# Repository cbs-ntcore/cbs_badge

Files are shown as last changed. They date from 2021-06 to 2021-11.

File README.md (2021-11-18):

This badge is designed to highlight digital fabrication techniques that are commonly
used in the [Neurotechnology Core](https://www.ntcore.org/)(NTCore) at the
[Center for Brain Science](http://cbs.fas.harvard.edu/) at Harvard University.

The NTCore works to accelerate and advance scientific progress through:
- design and fabrication of novel instrumentation
- user training and access to a shared fabrication space
- consultation on instrumentation use, design, fabrication, and purchase

By building a badge users will learn about:
- electronics design including making a custom printed circuit board (PCB) using the free and open source [KiCad](https://www.kicad.org/) design software
- electronics fabrication including soldering of surface mount electronics
- embedded programming using the [Arduino](https://www.arduino.cc/) environment
- designing mechanical parts using [Autodesk Fusion360](https://www.autodesk.com/products/fusion-360/) (free to academics)
- digital fabrication using 3D printing and laser cutting for rapid prototyping and production

We are happy to offer customized assistance. For the badge you can choose to:
- [Assemble pre-built parts](#assembling-your-badge)
- [Build (by soldering, laser cutting, etc...) and then assemble parts](#building-your-own-badge)
- Design your own parts (we're happy to help!)

# Assembling your badge

Your badge comes in 4 major parts and requires some minor assembly before use:
- Electronics
- Battery (CR2032)
- Laser cut case back cover
- 3D printed case

Below is a description of the assembly steps followed by a video of the assembly process.

- [ ] Install the battery into the electronics (positive side out).
- [ ] Insert the electronics into the case from the back making sure that the electronics slide behind the 6 plastic tabs.
- [ ] Slide the laser cut case back cover in place to lock the electronics into the case.
- [ ] Test the badge by pressing your finger against the two neurons at the bottom of the badge. If your hands are very dry you may need to slightly moisten your finger before touching the badge.

Click the image below for a short (~1 min) video showing the assembly process.

Assembly Video Link (https://www.youtube.com/watch?v=ZrBIpawWA10)

The hole at the top of the laser cut piece can be used to hang the badge from a lanyard, carabiner or cord.

If you are interested in more building experience, follow along with building the parts
of the badge.

# Building your own badge

Badge building involves 5 steps:
- [soldering electronic components to the badge printed circuit board](#soldering)
- [programming the microcontroller](#programming)
- [3D printing the main case body](#3d-printed-case)
- [laser cutting a custom case back cover](#lasercut-back-cover)
- [assembling your badge](#assembling-your-badge)

## Electronics

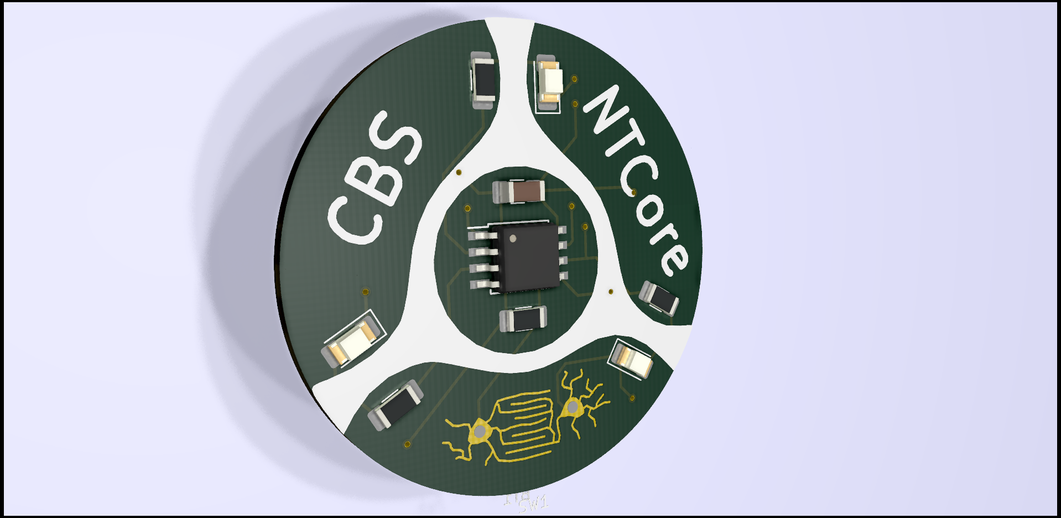
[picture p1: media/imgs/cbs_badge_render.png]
PCB Render Rough Render

### PCB
Although it is possible to fabricate your own printed circuit boards, the results are often less precise and more
time consuming than ordering a custom board. The cost of the board will depend on the difficulty in fabricating the design,
the lead time for the order and the quantity ordered. Designs that have traces (wires embedded in the PCB) that
are less than 6 mils (thousandths of an inch) or have many layers (pcbs are made by stacking layers of fiberglass, patterned
copper and other materials) are typically manufacturable at an increased cost or lead time. The design for this
badge is relatively simple and can be made by most low cost venders ('fab houses') including [OSHPark](https://oshpark.com/).
OSHPark is highly recommended as they produce high quality boards with a relatively short lead time (typically a week)
at a USA location allowing for overnight shipping. For their 'Prototype' service they charge $5 per square inch for a 2
layer PCB. The badge is 2.25 square inches costing $11.25 per board. When ordered with their 'Medium Run' bulk service
(which requires ordering at least 100 square inches) the cost drops to $2.25 per board.

### PCB and circuit design

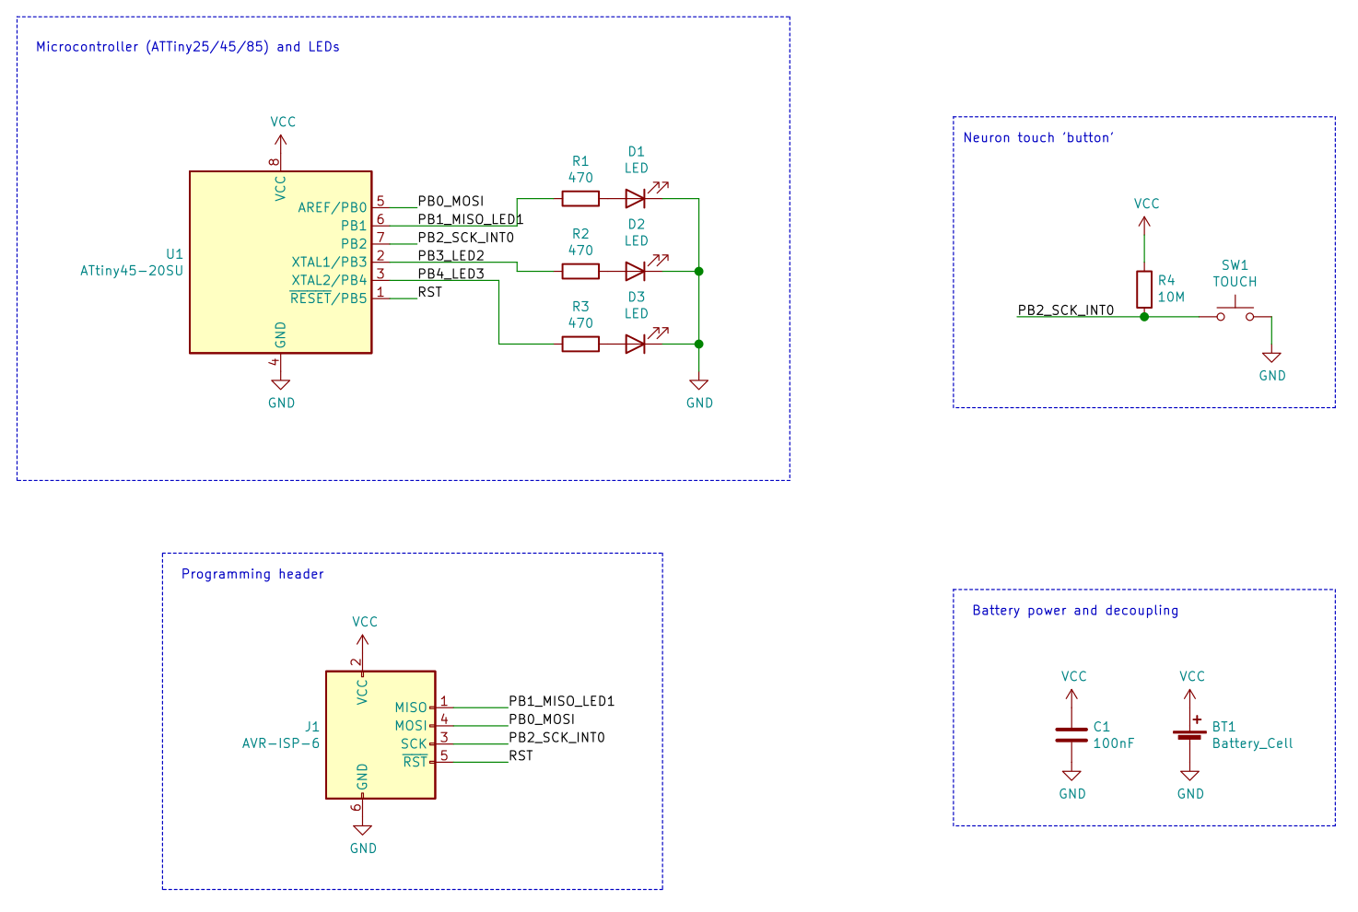
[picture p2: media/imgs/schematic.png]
schematic Schematic


[KiCad](https://www.kicad.org/) is a free and open source electronics design program that runs on all modern operating systems. It's design
process involves a number of steps often starting with making a schematic of the circuit you would like to build.
This schematic typically includes several components (including resistors, capacitors, connectors, integrated
circuits etc) connected using traces (wires embedded in the final PCB design). After a schematic is drawn some
automated tests should be run (electrical rules check or ERC) to check for incorrect or missing connections. The
final schematic and components can then be exported as a 'netlist', footprints (custom copper shapes that fit
specific components) can then be associated with the netlist components and then imported into the pcb
layout editor. In the pcb layout editor footprints are placed on a layered design (typical low cost boards
have 2 copper layers 'top' and 'bottom') and traces are drawn to connect footprints based on the connectivity
defined in the netlist. Before finalizing a design the pcb layout editor can run several automated checks
(design rule checks or DRC) to verify that your design matches the capabilities of the fab house (you will need
to input these design rules into the editor). Fab houses typically accept gerber files (a special file format
that contains images of layers of the pcb and other features needed for fabrication). However, some houses
including OSHPark will directly accept KiCad designs.

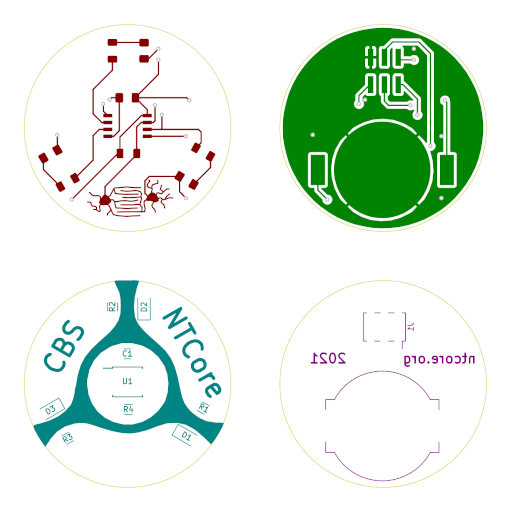
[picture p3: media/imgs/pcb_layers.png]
pcb PCB Layers


### Soldering

If you have not soldered before, [adafruit.com](adafruit.com) has a very good
[guide to soldering](https://learn.adafruit.com/adafruit-guide-excellent-soldering/surface-mount)
including tips on surface mount soldering.

All the electronic components are surface mount devices (SMD) which attach to
copper 'footprints' on the top or bottom of the badge.

It's often helpful to start with the shortest parts and solder the largest parts last
(connectors and in this case the battery tab). For this badge you might want to solder parts in the following order:
- ATTiny (U1): the black 8 pin chip that goes in the middle
- Capacitor (C1): the small tan colored device
- Resistors (R1-R4): a 106 (10 MOhm) resistor (R4) and 3 x 471 (470 Ohm) resistors one for each LED (R1-3)
- LEDs (D1-3): light emitting diodes, clear side up, green arrow down
- battery holder (on back): make sure the battery slides in from the edge of the badge

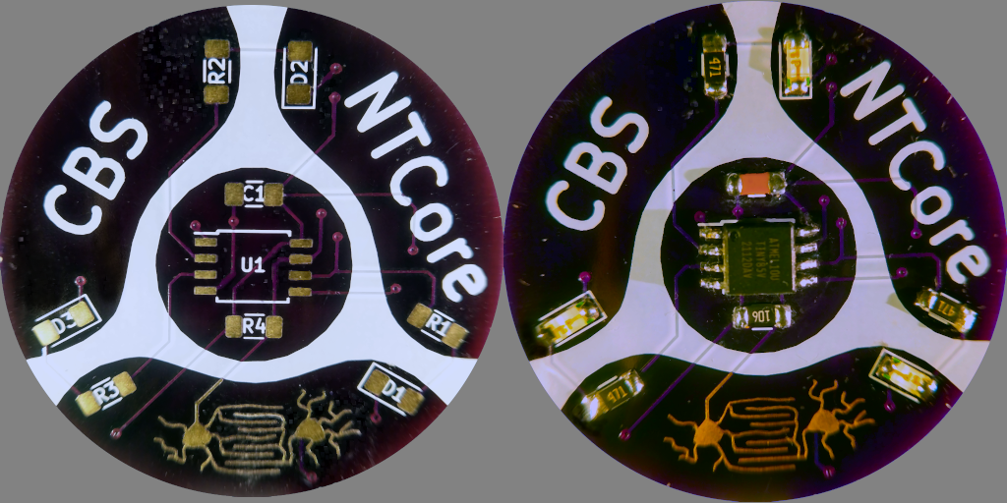
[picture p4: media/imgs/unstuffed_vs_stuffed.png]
Stuffed Board Stuffed board


Some parts (the LEDs and ATTiny) only work when connected in one orientation.
Be sure to connect:
- the pin on the ATTiny next to the dot to the pad marked with an extended line
- the green marked ends of the LEDs with the closed end of the lines

Soldering SMD electronics takes some practice and a few tips can make the
process much easier. One useful technique is to solder 1 pin at the corner
of a part. This pin can be reheated and the part position
adjusted with forceps while the solder is molten. When the part is correctly
aligned the opposite pin can be soldered to lock the part in place before
soldering the remaining pins.

It's time to solder the components on the front of the badge:
- [ ] U1: black 8 pin ATTiny, note the orientation
- [ ] C1: tan capacitor
- [ ] R4: 106 (10 MOhm) resistor
- [ ] R1: 471 (470 Ohm) resistor
- [ ] R2: 471 (470 Ohm) resistor
- [ ] R3: 471 (470 Ohm) resistor
- [ ] D1: LED, note the orientation
- [ ] D2: LED, note the orientation
- [ ] D3: LED, note the orientation

Finally, flip over the badge to prepare to solder on the battery clip.

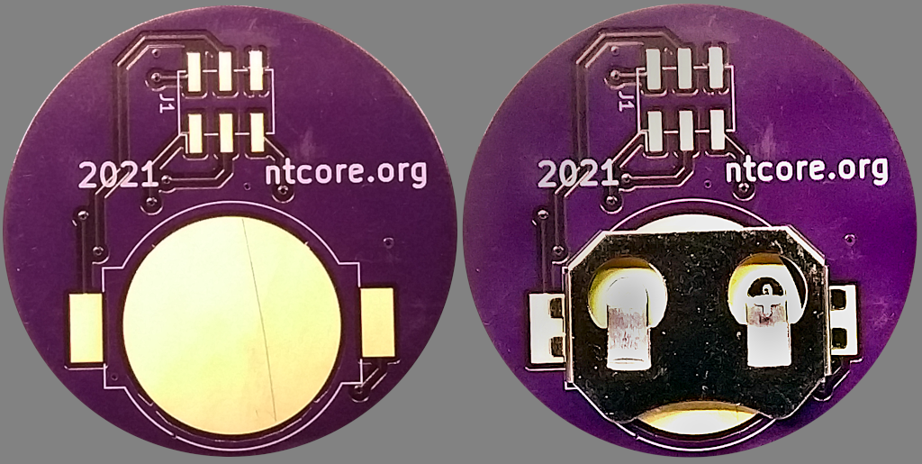
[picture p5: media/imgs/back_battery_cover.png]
Battery Cover


Solder the back battery holder taking care as the iron will quickly heat
up the entire metal clip. Allow the clip to cool down between applications of
heat while adjusting the clip. Be sure to add plenty of solder to create a
solid connection that will resist the spring force of the clip when the battery
is inserted.

## Software
### Programmable electronics using microcontrollers

The badge contains a microcontroller, a small computer designed to produce and sample digital
and analog signals. The microcontroller can be programmed (more on this below) to produce precisely
timed pulses, read and record analog voltages, control other electronics (lights, sensors, motors, etc),
perform complicated logic (state machines, event loops) and many other tasks. Many types of microcontrollers
are available with different amounts of processing power, number of connections and specialized hardware
(including wifi and other wireless communication). The badge circuit uses a simple and low cost ATTiny.
This ATTiny has only 8 connections (pins) and requires only a program and a connection to power and
ground to function. For the badge 3 pins are connected to light emitting diodes (LEDs) and one more pin
is connected to a custom neuron footprint used as a touch sensor.

### Embedded programming using Arduino

[Arduino](https://www.arduino.cc/) is a beginner friendly environment for writing programs for and configuring microcontrollers. There are
many official and non-official 'Arduino compatible' boards which can be programmed with the Arduino
integrated development environment (IDE). Arduino programs are written in the C++ programming language
and use functions that simplify the process of setting or reading the state of digital and analog pins
and other aspects of using a microcontroller. Development using Arduino starts with installing the IDE,
adding support for the board you'd like the use, installing any required libraries, and then writing
your program and 'uploading' it to your board. Most boards can be programmed over USB. However, the
badge uses a simpler method called 'in circuit serial programming' (ICSP) that requires a custom
programmer (such as the [Pocket AVR Programmer](https://www.sparkfun.com/products/9825) or 
[USBtinyISP](https://www.adafruit.com/product/46)). To compile code for the ATTiny you will need to
install support for the ATTiny from here: [https://github.com/damellis/attiny](https://github.com/damellis/attiny)

For a detailed course on using Arduino please see the
['Arduino for Biologists' nanocourse](https://github.com/HMS-RIC/ArduinoNanocourse).

neurongif Neuron firmware

The badge 'firmware' (software for embedded hardware) simulates 3 neurons connected in a ring with 3
model excitatory synapses. The spike output of each neuron is mapped to a different LED which flashes
when the neuron spikes. When the touch sensor (copper neurons at the bottom of the badge) is touched, the
microcontroller wakes up from 'sleep' (a low power mode where very few features are active) and 
initializes the neural network by setting the synaptic weights to a low value. As the network runs,
random simulated currents are injected into the 3 neurons causing them to initially spike in a random
pattern. These spikes trigger time-dependent changes in the synaptic weights. The lack of inhibition
and asymmetry in the plasticity causes unbound excitation in the circuit and the network often
quickly converges to a state of continuous fast firing. The network will continue to run as long
as the touch sensor is held. When the touch sensor is released the microcontroller will reenter
'sleep' mode to extend battery life.

### Programming

Make sure there is no battery in the badge (the programmer will power the
electronics). Press the badge against the programmer aligning the upper 
white portion of the logo with the notch in the programming jig as shown in the
image below.

Programming


While holding the badge in place run "Sketch->Upload Using Programmer" in the
Arduino program. Some of the LEDs should blink and when the program says
"Done uploading" your badge is programmed.

Remove the badge from the programmer, insert the battery and test the badge
by pressing the neurons at the bottom of the badge while not touching the
battery clip on the back.

## Case
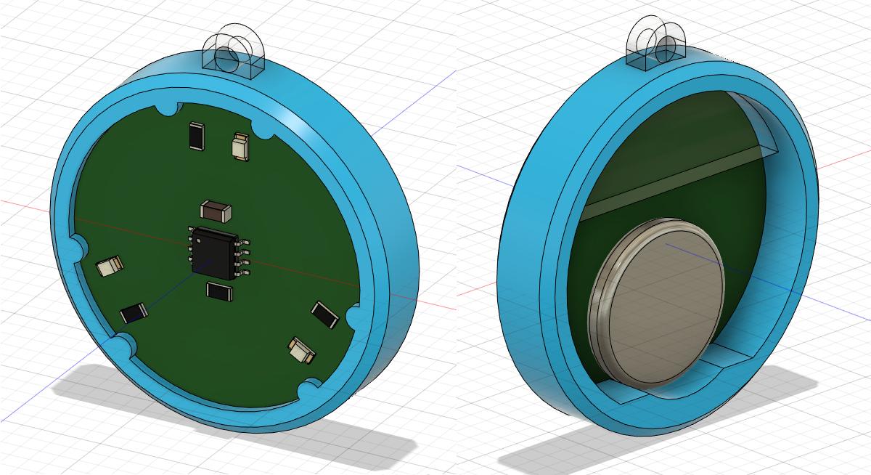
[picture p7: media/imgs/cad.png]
Case CAD


### Computer aided design (CAD) using Autodesk Fusion360

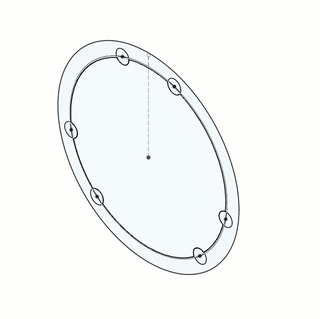
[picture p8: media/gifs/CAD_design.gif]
CAD CAD design


Although simple 2D mechanical parts can be designed in Inkscape, Adobe Illustrator or other vector
graphics programs, 3D parts and assemblies are often designed in specialized computer aided design
(CAD) software. The badge case was designed in [Autodesk Fusion360](https://www.autodesk.com/products/fusion-360/)
(free to academics) and involved a typical process where 2D sketches on reference planes are 'extruded' to form 3D shapes. Each
new 3D shape can be joined with previous shapes or be used to cut custom shaped holes out of existing
parts. This process creates a final (or multiple) 3D shapes and a recorded history of how these
parts were designed. This history can be edited and replayed to generate part revisions or to
adapt a single design to multiple applications. For the badge, 2 parts were designed: a 
case designed for easy 3D printing and a customizable back cover designed for laser cutting.

### 3D printed case

3D printing

3D printing is a relatively automated process for translating a digital design to a physical
object. Although many materials can be 3D printed with often very different processes, one of the
most common methods for 3D printing is fused deposition modeling (FDM) using a plastic filament, 
polylactic acid (PLA). FDM printing involves heating up and forcing (extruding) PLA through a
circular nozzle (0.4 mm in diameter) that is mounted to a XYZ movement system. By depositing
and fusing overlapping 2D layers, complex 3D shapes can be created. Preparing a design for FDM
printing involves:
- exporting a solid model (in STL file format) from your CAD software
- importing the STL into a 'slicer' program that:
    - cuts the model into 2D layers
    - adds any necessary support material to deal with unsupported overhangs (where a higher 2D layer has no plastic underneath
to join to)
    - generates a sequence of movements (GCODE) to command the 3D printer to make the part
- loading and running the GCODE on a suitable 3D printer
- finally removing any support material and finishing your part

### Lasercut back cover

Lasercutting is a common technique for cutting 2D shapes out of flat sheets of plastic (typically
acrylic). A high powered (75 watt) CO2 laser is focused on the surface of the plastic at a position
determined by computer controlled XY movement. This focused light quickly ablates the plastic
under the beam and by moving the cut position in various paths, flat 2D parts can be produced.
For simple designs, vector graphics programs (Inkscape, Adobe Illustrator, Corel Draw) can be used to simply
draw the paths the laser should follow and for more complex designs sketches can be exported from
CAD software in a suitable format (DXF). For most 2D geometries lasercutting is significantly
faster, more accurate and produced a better finished part compared to 3D printing.

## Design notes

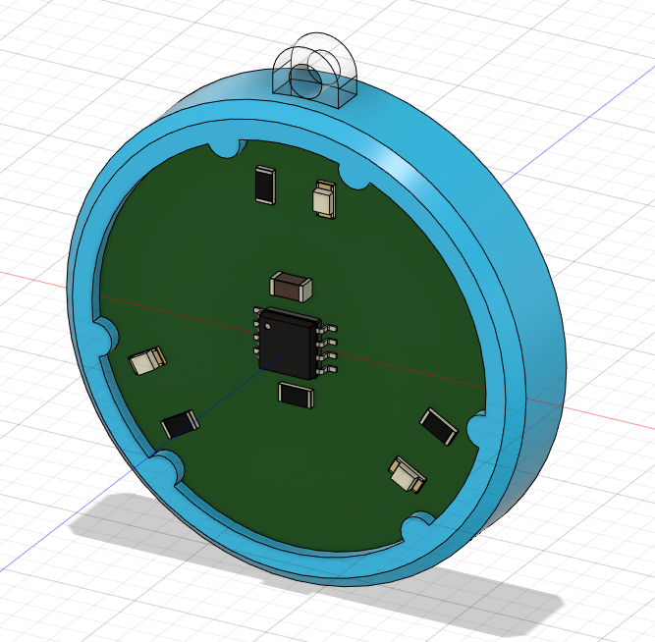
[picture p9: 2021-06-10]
media/imgs/cad_front.png

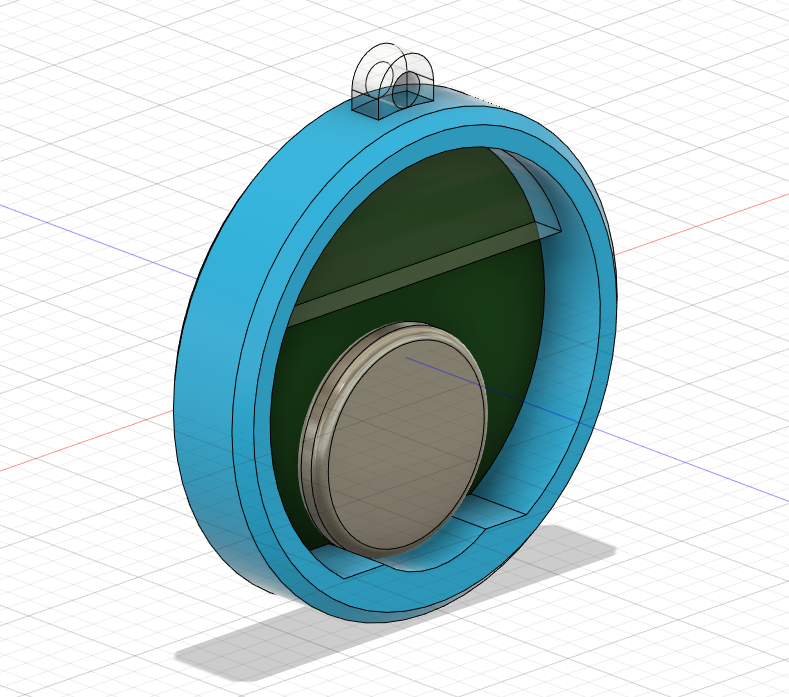
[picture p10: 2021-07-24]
media/imgs/cad_back.png

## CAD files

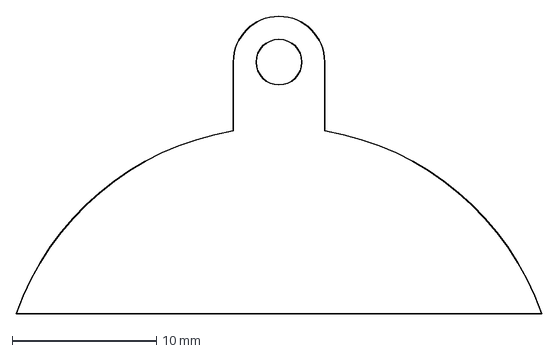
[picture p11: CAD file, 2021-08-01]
blank_back_case_cover.dxf
36.5 x 20.6 mm

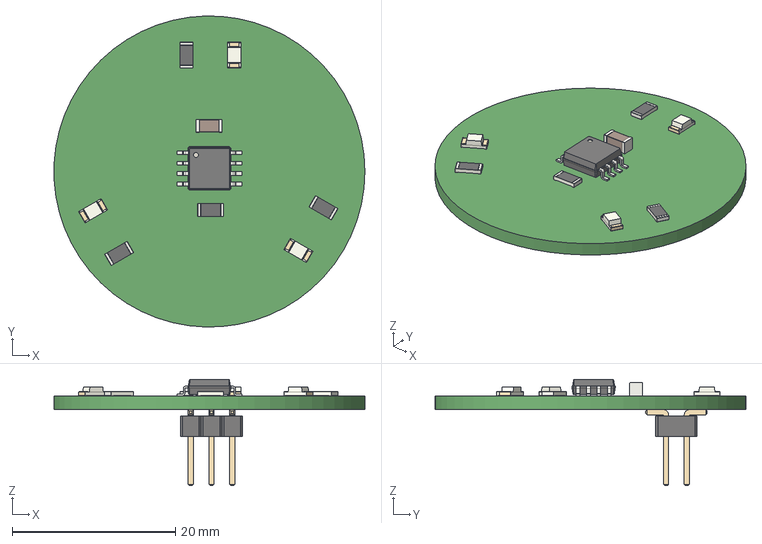
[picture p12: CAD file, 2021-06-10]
cbs_badge/cbs_badge.step
38.1 x 38.1 x 13.0 mm

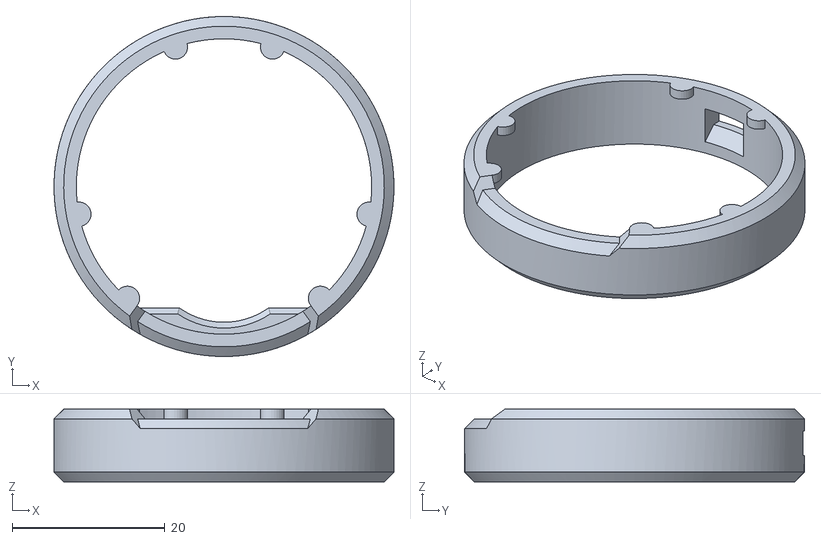
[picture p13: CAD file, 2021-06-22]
case.stl
44.4 x 44.5 x 9.53

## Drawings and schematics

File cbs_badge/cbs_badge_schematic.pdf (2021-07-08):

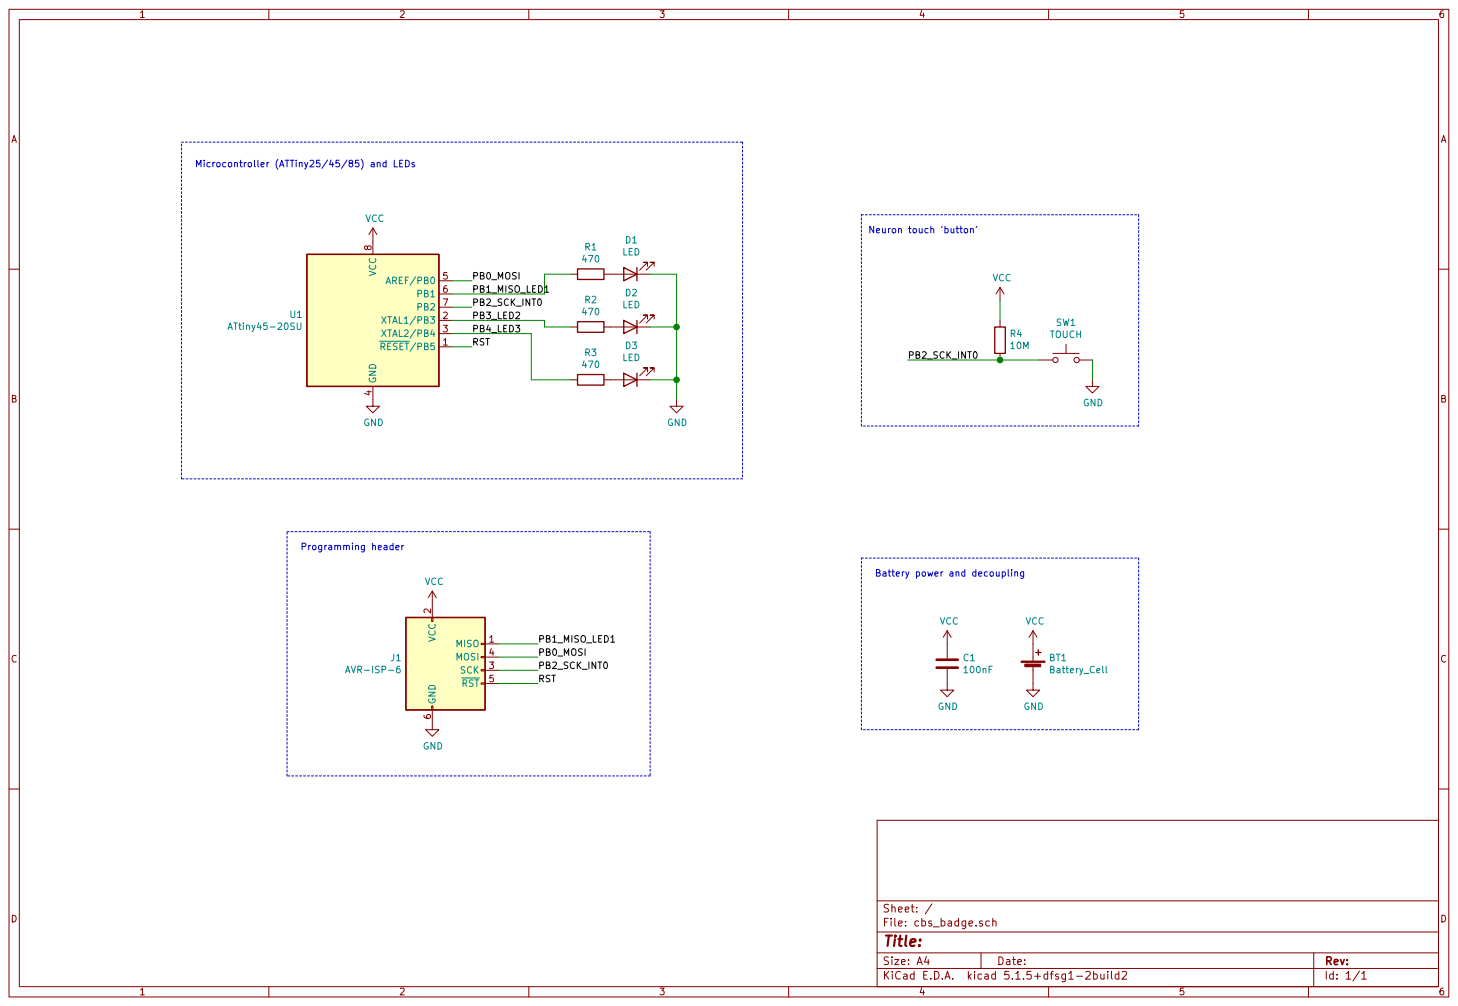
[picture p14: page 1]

Battery power and decoupling Neuron touch 'button' Microcontroller (ATTiny25/45/85) and LEDs

File: cbs_badge.sch Sheet: / GND

2 SCK 3 MOSI 4 RST 5 GND

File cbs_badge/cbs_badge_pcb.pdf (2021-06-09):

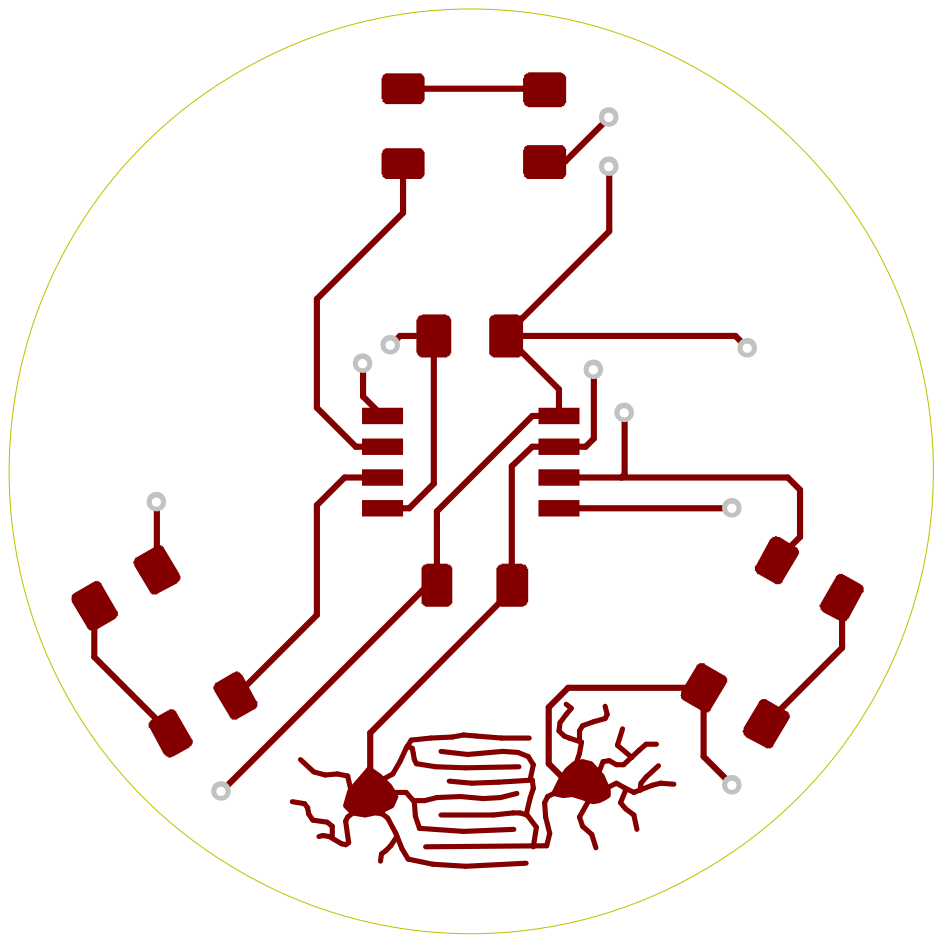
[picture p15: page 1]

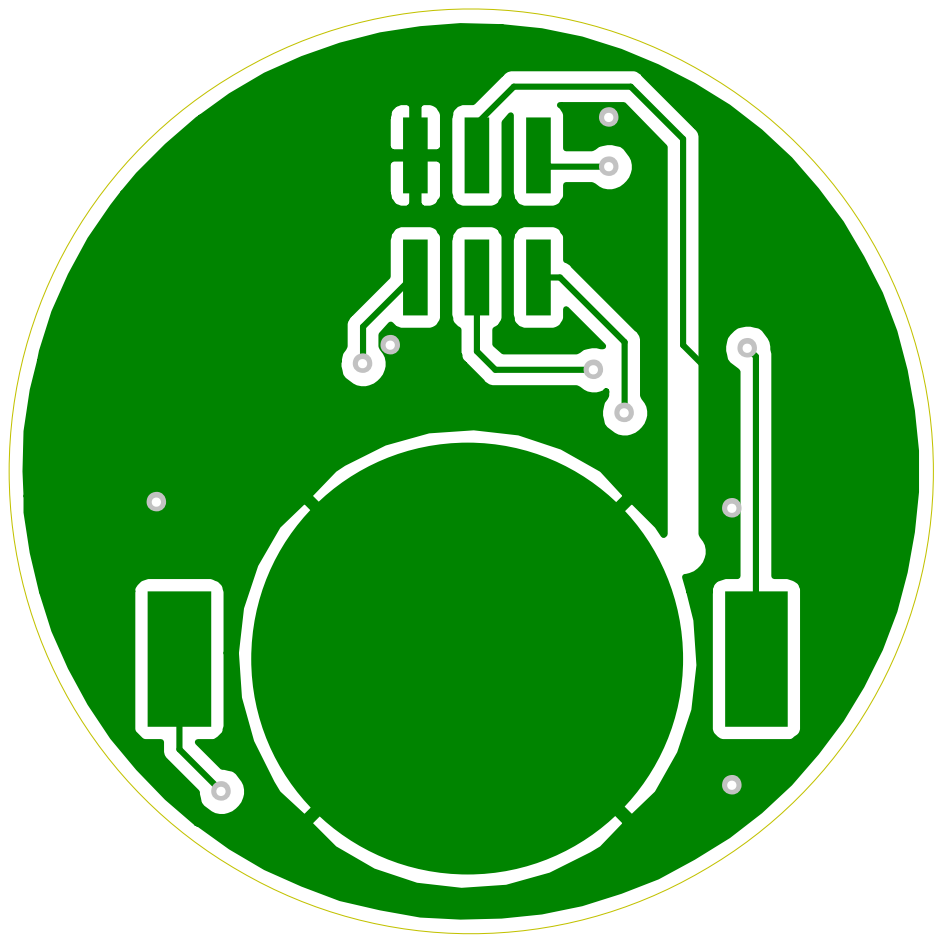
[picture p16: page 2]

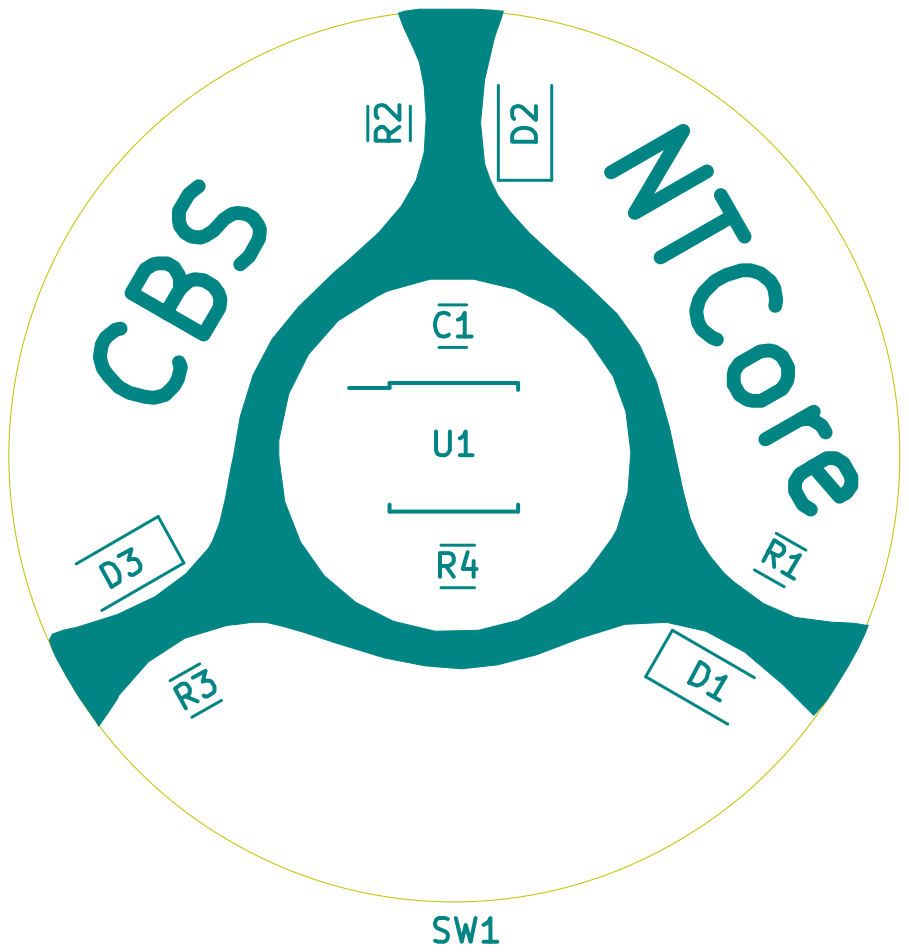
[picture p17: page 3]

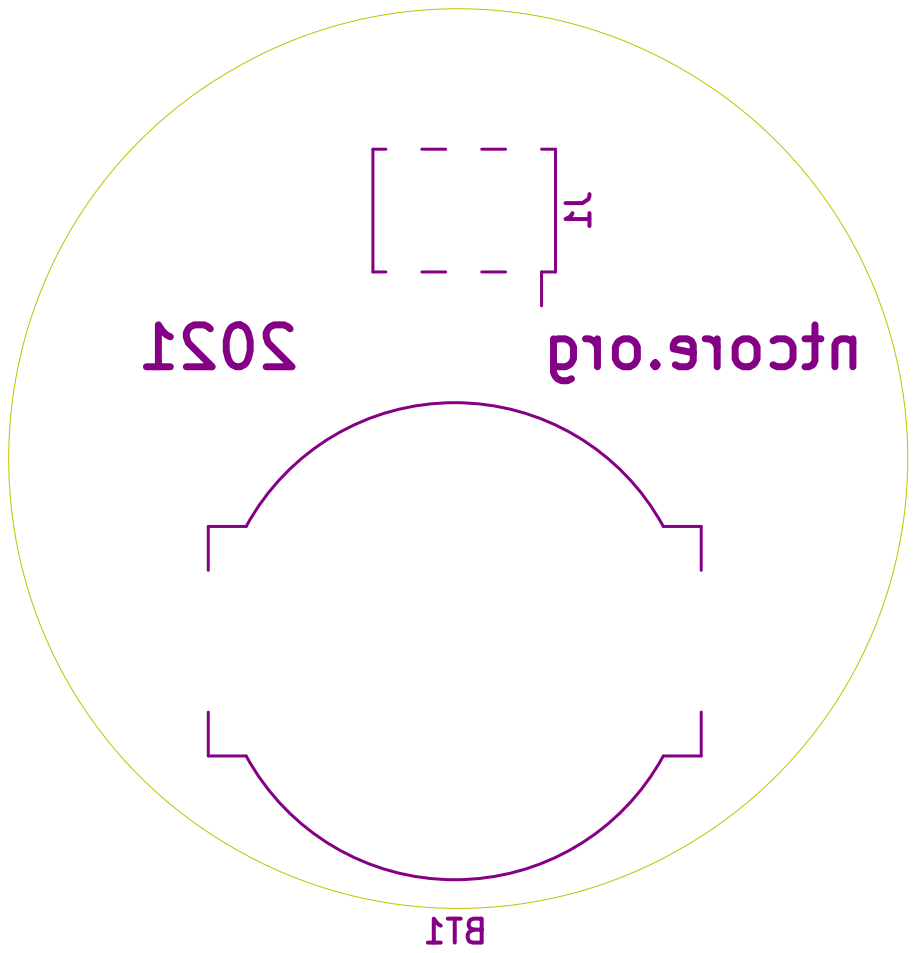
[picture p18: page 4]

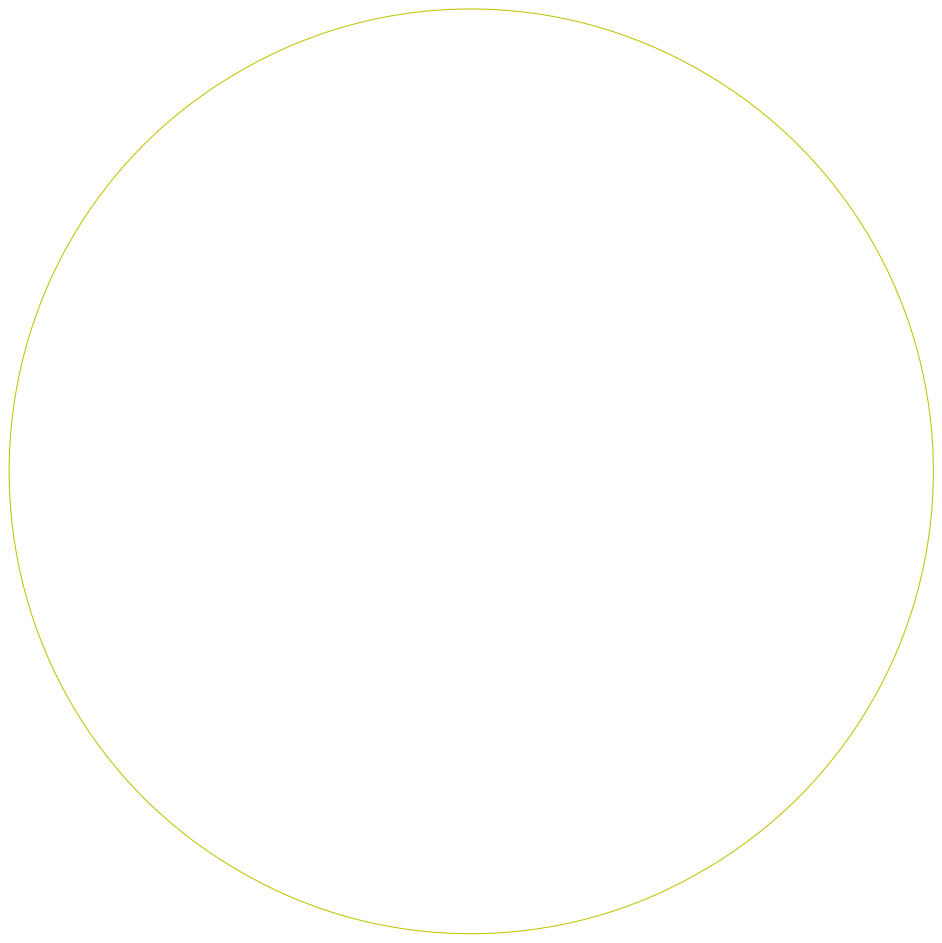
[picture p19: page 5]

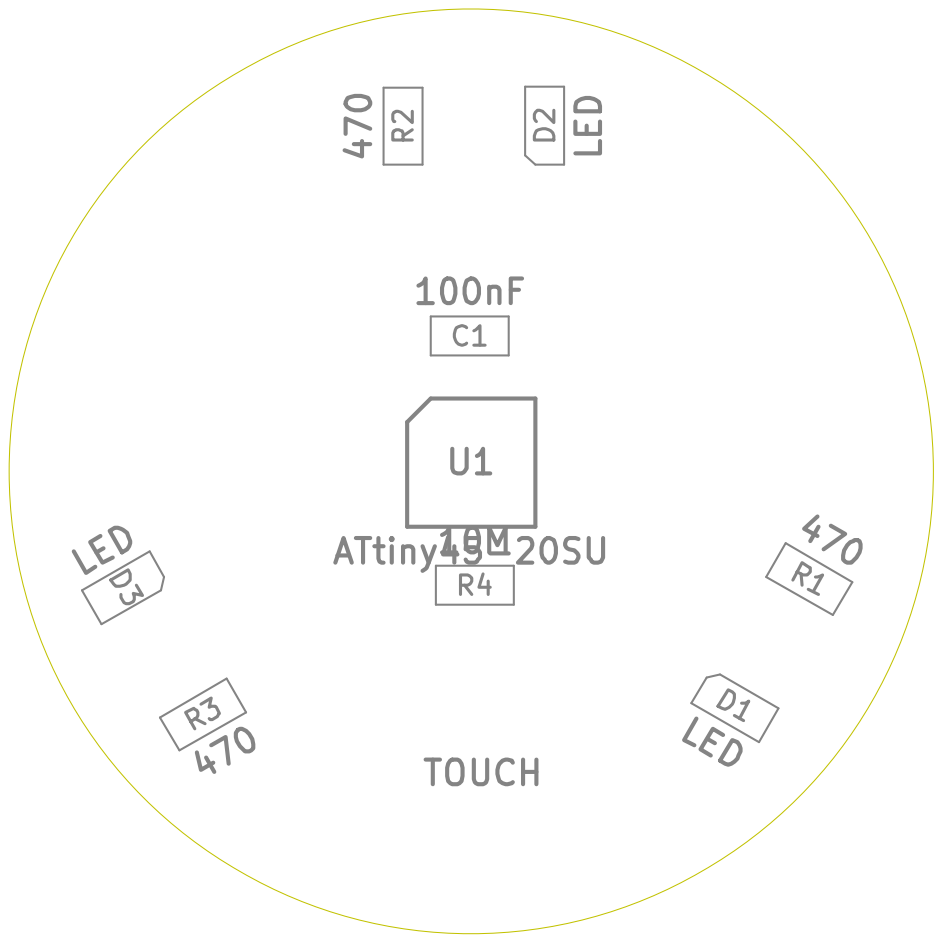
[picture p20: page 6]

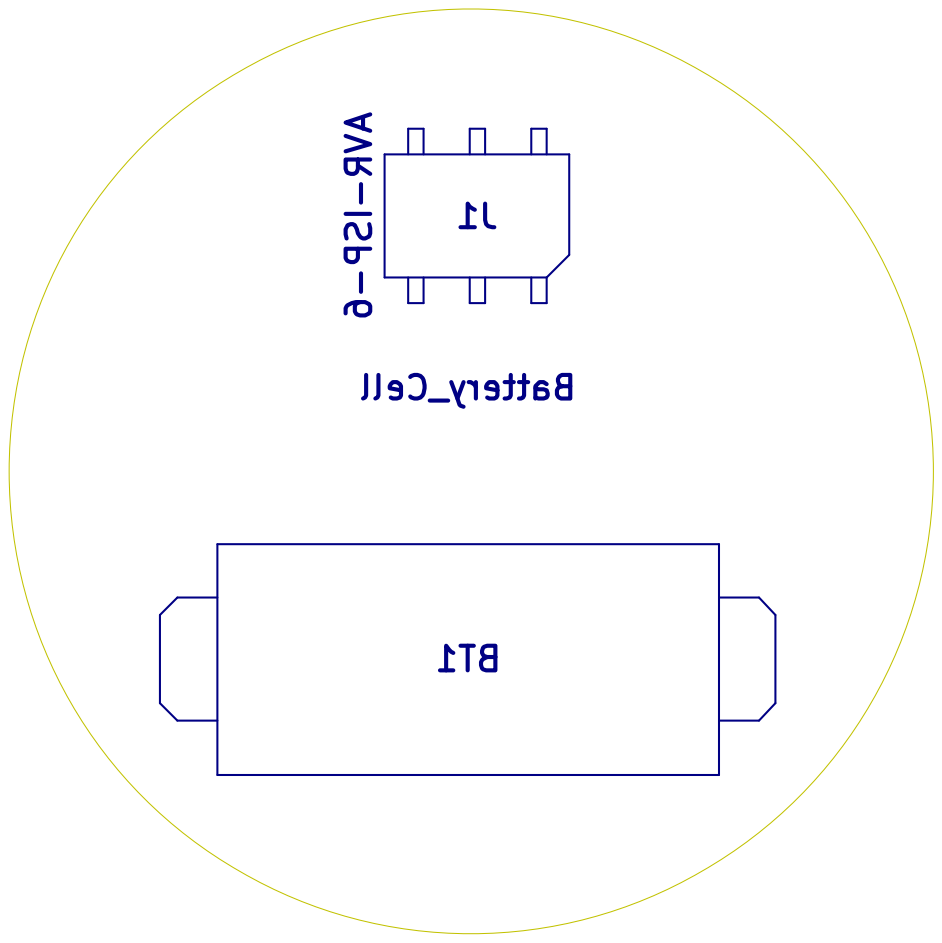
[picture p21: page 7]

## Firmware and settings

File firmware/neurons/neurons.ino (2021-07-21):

/*
     -
    / \    Neural Network CBS NTCore Badge firmware
---/   \  ---------------------------------------------
        \/

This code is a demonstration of the badge features.

'Press' the two neurons at the bottom of the badge to wake it up (if you have
dry hands you may need to wet your finger).

When the badge wakes up, it will begin simulation of a simple neural network
consisting of 3 neurons connected with 3 synapses. The network starts with
low synaptic weights and low overall bias producing a low spontaneous firing
rate. When neurons spikes the strengths of connected synapses are updated
based on a simple asymmetric spike time dependent plasticity. The asymmetry
and lack of inhibition encourages the network to settle into a state of
continuous high firing rate after a short time. To encourage transition to
this state, global network bias is increased in the absense of firing.

The below code contains comments intended to introduce some features of
microcontroller programming and should hopefully serve as teasers for
the utility and productivity that can be gained by learning how to use
the Arduino ecosystem.

This firmware is designed to run on the ATTiny85 installed on the badge.
It is written in C++ and uses the Arduino ecosystem for rapid code development.
To build the code, install the Arduino IDE and the ATTiny 'core' found here:

https://github.com/damellis/attiny

By following the installation instructions in the link above you can add
support for programming ATTiny microcontrollers using the Arduino IDE.

To program the badge you will need a AVR programmer like this one:

https://www.sparkfun.com/products/9825

Open this file in the Arduino IDE, select 'ATTiny25/45/85' in the Tools->Board
menu and 'USBTinyISP' in the Tools->Programmer menu. Next, connect the ICSP
header and select 'Upload Using Programmer' in the Sketch menu to compile and
upload the code.
*/


// Include code located within the installed 'core' used to put the attiny
// to 'sleep', a low power mode where only minimal features are active.

#include <avr/sleep.h>


// Define, or give readable names to pins that are connected to lights and
// the touch 'button'. These defines allow the below code to use 'LED1_PIN'
// instead of the less readable '1' when referring to the pin connected to the
// first light.

#define LED1_PIN 1
#define LED2_PIN 3
#define LED3_PIN 4
#define TOUCH_PIN 2


// Defines can also be used to set 'constants' such as the threshold for neuron
// activation and the number of timesteps for the refractory period.

#define THRESH_MV 70
#define REFRACTORY_TIMESTEPS 1


// Declare some global variables that will be available everywhere in the code
// below.

unsigned long simulation_timestep = 0;
float bias = 0;


// Lookup tables (luts) are used to store pre-computed values that are
// frequently used or take too much time to compute. The exponential function
// of the learning rule is one example precomputed below.

uint8_t delta_lut[] = {
  50, 47, 45, 43, 40, 38, 37, 35, 33, 31, 30, 28, 27, 26, 24, 23, 22,
  21, 20, 19, 18, 17, 16, 15, 15, 14, 13, 12, 12, 11, 11, 10, 10,  9,
  9,  8,  8,  7,  7,  7,  6,  6,  6,  5,  5,  5,  5,  4,  4,  4,  4,
  3,  3,  3,  3,  3,  3,  2,  2,  2,  2,  2,  2,  2,  2,  1,  1,  1,
  1,  1,  1,  1,  1,  1,  1,  1,  1,  1,  1,  0};
uint8_t max_delta = sizeof(delta_lut) / sizeof(uint8_t);


// Lookup table of normally distributed 'random' numbers

int8_t randn_numbers[] = {
  -5,   3,  -9,  -5,   7,  -4,  -9,   3,  -5,   0,  -1,   4,   4,
   0,   2,  -5,   3,  10,  -9,  -1,  -7,  -3,  -1,  -3,   4,  -3,
   1,  -6,  -5,   0,  -1,  -1,  -3,   0,  -2,   6,  -1,  -1,   5,
   6,   0,   8,  -5,  12,  -1,   5,  -2,  -1,   0,  12,  -5,   2,
   3,  -3,   3,   6,   2,  -1,   1,  -2,   1,   0,  -6,   0,  -4,
  -10,  -2,  -3,  -1,   2,  -6,   0,   3,   5,   1,   5,   0,  -8,
   4,  -1,   0,   8,   3,  -3,   4,   0,   6,   1,   2,  -7,   0,
   0,  -5,   0,   3,   7,  -6,  -6,   4,  -8};
uint8_t n_randn_numbers = sizeof(randn_numbers) / sizeof(int8_t);


// C++ is object oriented and supports classes.
// This 'Neuron' class contains variables and functions associated with
// simulating the neuron portion of the network. After defining a class,
// instances of that class can be created that have separate variables
// called attributes (such as 'mv' for membrane voltage) and functions
// called methods (such as 'update').

class Neuron {
  public:
    Neuron();
    float mv, syn_i;
    int ref;
    bool spike;
    void update();
};


// The constructor is called when a class instance is created and
// should be used to set attributes to starting values.

Neuron::Neuron() {
  mv = 0;
  syn_i = 0;
  ref = 0;
  spike = false;
}


// Class methods have access to attributes of the class (mv refers to the
// membrane voltage of the class instance on which 'update' was called).

void Neuron::update() {
  spike = false;
  if (ref) {
    ref -= 1;
    mv = 0;
    return;
  }
  mv += syn_i;
  mv *= 0.99;
  if (mv > THRESH_MV) {
    spike = true;
    ref = REFRACTORY_TIMESTEPS;
    mv = 0;
  }
  if (mv < 0) {
    mv = 0;
  }
  syn_i = 0;
}


// Define a 'Synapse' class with pointers (references) to pre and post
// synaptic neuron class instances.

class Synapse {
  public:
    Synapse(Neuron* presyn, Neuron* postsyn);
    float current;
    float max_current;
    unsigned long pre_st, post_st;
    void update();
  private:
    Neuron *pre;
    Neuron *post;
};

Synapse::Synapse(Neuron* presyn, Neuron* postsyn) {
  pre = presyn;
  post = postsyn;
  current = 0;
  max_current = 1;
  pre_st = 0;
  post_st = 0;
}

void Synapse::update() {
  if (pre->spike) {
    pre_st = simulation_timestep;
  }
  if (post->spike) {
    post_st = simulation_timestep;
  }
  if (pre_st && post_st) {
    int delta = post_st - pre_st;
    float mag;
    if (delta > 0) {
      if (delta < max_delta) {
        mag = delta_lut[delta];
        max_current += mag;
      }
    } else {
      if (-delta < max_delta) {
        mag = delta_lut[-delta];
        max_current -= mag * 0.1;
      }
    }
    pre_st = 0;
    post_st = 0;
  }
  if (pre->spike) {
    current = max_current;
  } else {
    current *= 0.9;
  }
  post->syn_i += current;
}


// Instantiate 3 neurons and synapses connecting them in a ring.

#define N_NEURONS 3
Neuron neurons[] = {Neuron(), Neuron(), Neuron()};
Synapse synapses[] = {
  Synapse(&(neurons[0]), &(neurons[1])),
  Synapse(&(neurons[1]), &(neurons[2])),
  Synapse(&(neurons[2]), &(neurons[0])),
};


// Declare an array of pins used to map neurons to lights.

int pins[] = {LED1_PIN, LED2_PIN, LED3_PIN};


// Define a function to reset the circuit.

void reset_circuit() {
  simulation_timestep = 0;
  for (int i=0; i<N_NEURONS; i++) {
    neurons[i].spike = false;
    neurons[i].mv = 0;
    synapses[i].current = 0;
    synapses[i].max_current = 1;
  }
}


// Define a function to run the circuit for a single timestep.

void run_circuit() {
  // first update all synapses so they can use spikes from the previous
  // timestep to update synaptic weights and inject current into post-synaptic
  // neurons
  for (int i=0; i<N_NEURONS; i++) {
    synapses[i].update();
  }

  // increase the global bias of the network (this is reset below on any spike)
  bias += 0.05;

  // update all the neurons
  for (int i=0; i<N_NEURONS; i++) {
    Neuron *n = &(neurons[i]);

    // add some random noise and bias currents
    n->syn_i += randn_numbers[random(0, n_randn_numbers)] + bias;

    n->update();

    // if a neuron spiked, turn on the corresponding light
    if (n->spike) {
      digitalWrite(pins[i], HIGH);
      bias = 0;
    } else {
      digitalWrite(pins[i], LOW);
    };
  }
  simulation_timestep += 1;
}


// Define a special function a 'interrupt service routine' or ISR that runs
// when a the touch 'button' is pressed. This interrupt will be triggered
// even when the microcontroller is sleeping.

ISR(INT0_vect) {
  bitClear(GIMSK, INT0);  // Disable INT0 interrupt
  sleep_disable();
  // U+1F480 base64:aHR0cHM6Ly9za3VsbGN0Zi5jb20v
}


// Before putting the microcontroller to sleep, turn off lights and disable
// some peripherals.

void sleep() {
  digitalWrite(LED1_PIN, LOW);
  digitalWrite(LED2_PIN, LOW);
  digitalWrite(LED3_PIN, LOW);

  // Disable ADC - saves about 324.5uA in sleep mode!
  ADCSRA = 0;

  set_sleep_mode(SLEEP_MODE_PWR_DOWN);
  sleep_enable();
  // Before fully going to sleep (sleeping the cpu) enable the INT0 interrupt
  // so the ISR will be triggered when the touch 'button' is pressed
  noInterrupts();
  bitSet(GIMSK, INT0);  // Enable INT0 interrupt
  interrupts();
  sleep_cpu();
}


// Arduino uses 2 special functions, 'setup' and 'loop'.
// setup is run once when the microcontroller is powered on.

void setup() {
  // most pins support multiple functions including digital input and output.
  // Set all pins connected to lights as digital outputs.
  pinMode(LED1_PIN, OUTPUT);
  pinMode(LED2_PIN, OUTPUT);
  pinMode(LED3_PIN, OUTPUT);

  // Set the state of the light pins to 'LOW' which pulls the pin to ground
  // disabling the light.
  digitalWrite(LED1_PIN, LOW);
  digitalWrite(LED2_PIN, LOW);
  digitalWrite(LED3_PIN, LOW);
  
  // This is an example of lower level access to microcontroller functions
  // which are often abstracted away using the Arduino ecosystem. In this case
  // fully disable the analog to digital converter (to save power) by writing
  // directly to a special memory address (register) defined in the core as
  // ADCSRA (ADC status and control register A)
  ADCSRA = 0;
}


// loop is run after setup and repeats until power is removed.

void loop() {
  // put the microcontroller to sleep, this function will return when sleep
  // is ended because of a touch 'button' press
  sleep();

  // first reset the circuit to a default, low activity state
  reset_circuit();

  // run the circuit for as long as the touch 'button' is pressed
  while (!digitalRead(TOUCH_PIN)) {
    run_circuit();
  }
}

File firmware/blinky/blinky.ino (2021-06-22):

#include <avr/sleep.h>

#define LED1_PIN 1
#define LED2_PIN 3
#define LED3_PIN 4
#define TOUCH_PIN 2

#define DELAY_MS 100


ISR(INT0_vect) {
  bitClear(GIMSK, INT0);  // Disable INT0 interrupt
  sleep_disable();
}

void sleep() {
  digitalWrite(LED1_PIN, LOW);
  digitalWrite(LED2_PIN, LOW);
  digitalWrite(LED3_PIN, LOW);
  // Disable ADC - saves about 324.5uA in sleep mode!
  ADCSRA = 0;

  set_sleep_mode(SLEEP_MODE_PWR_DOWN);
  sleep_enable();
  noInterrupts();
  bitSet(GIMSK, INT0);  // Enable INT0 interrupt
  interrupts();
  sleep_cpu();

  // Restore ADC
  //ADCSRA = oldAdc;
}

void setup() {
  pinMode(LED1_PIN, OUTPUT);
  pinMode(LED2_PIN, OUTPUT);
  pinMode(LED3_PIN, OUTPUT);
  digitalWrite(LED1_PIN, LOW);
  digitalWrite(LED2_PIN, LOW);
  digitalWrite(LED3_PIN, LOW);
  
  // Disable ADC - saves about 324.5uA in sleep mode!
  ADCSRA = 0;
}

void loop() {
  sleep();

  while (!digitalRead(TOUCH_PIN)) {
    // blinky!
    digitalWrite(LED1_PIN, HIGH);
    delay(DELAY_MS);
    digitalWrite(LED3_PIN, LOW);
    delay(DELAY_MS);
    digitalWrite(LED2_PIN, HIGH);
    delay(DELAY_MS);
    digitalWrite(LED1_PIN, LOW);
    delay(DELAY_MS);
    digitalWrite(LED3_PIN, HIGH);
    delay(DELAY_MS);
    digitalWrite(LED2_PIN, LOW);
    delay(DELAY_MS);
  }
}

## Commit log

2021-06-09 initial badge prototype electronics
    [cbs_badge.kicad_pcb, cbs_badge.sch]
2021-06-09 minor routing changes
    [cbs_badge.kicad_pcb]
2021-06-09 add pdfs of schematic and pcb
2021-06-10 add bom items to schematic
    [cbs_badge.sch]
2021-06-10 add rendering of front and back and step export of pcb
    [case.stl, cbs_badge.step]
2021-06-11 ordered from oshpark
    [cbs_badge.kicad_pcb]
2021-06-22 update case
    [case.stl]
2021-07-07 add description to README CAD heading
2021-07-08 clean up schematic, add to README
    [cbs_badge.sch]
2021-07-20 add sparkfun programmer and 'fix' pcb layers image
2021-07-24 working on electronics assembly instructions
2021-07-24 update badge assembly instructions
2021-07-24 crop case back image
2021-07-24 combine front and back case CAD images
2021-07-28 update readme with correct resistor values, more verbose assembly checklist
2021-08-01 add blank back case cover design file
    [blank_back_case_cover.dxf]
